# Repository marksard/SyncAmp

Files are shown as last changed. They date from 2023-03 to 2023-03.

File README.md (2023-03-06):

# Synthesizer Sync Output Voltage Amplifier

A comparator-type amplifier that provides 5V Sync voltage for small instruments such as Teenage Engineering PO-32 and Paripi Destroyer.

[blog](https://marksard.github.io/2023/02/23/make-line-mixer/)

  
  

## Usage

Connect to SyncIn from a small instrument such as Teenage Engineering PO-32, Paripi Destroyer, etc.  
From Sync Out, connect to the instrument with Sync In.  
Adjust the Threshold knob until the LED flashes moderately in time with the pulse of the Sync voltage. If it syncs, you have succeeded.  

## Spec

### Input

3.5mm phone jack (TS)  
DC input is available.  

### Thresold Setting

As known as V ref.  
Range of values 0V to 2.5V.  

### Output

3.5mm phone jack (TS)  
Range of values 0V to 4.7V.  

### Power supply

- 9V

## Schematic



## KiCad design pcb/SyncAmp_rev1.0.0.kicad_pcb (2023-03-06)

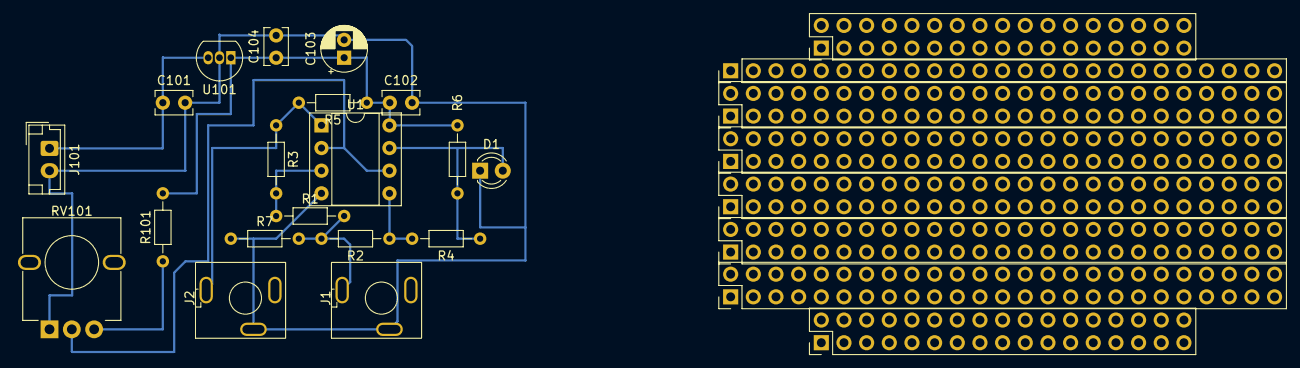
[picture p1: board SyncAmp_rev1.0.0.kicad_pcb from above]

Board: 2 copper layers, 19 parts (0 on the bottom side), 10 nets.

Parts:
C101: 0.33u; C_Rect_L4.0mm_W2.5mm_P2.50mm
C102, C104: 0.1u; C_Rect_L4.0mm_W2.5mm_P2.50mm
C103: 47u; CP_Radial_D5.0mm_P2.00mm
D1: LED; LED_D3.0mm
J1: Sync In; MJ-355W
J2: Sync Out; MJ-355W
J101: Barrel_Jack; JST_EH_B2B-EH-A_1x02_P2.50mm_Vertical
R1, R2, R7, R101: 10k; R_Axial_DIN0204_L3.6mm_D1.6mm_P7.62mm_Horizontal
R3, R4: 10Meg; R_Axial_DIN0204_L3.6mm_D1.6mm_P7.62mm_Horizontal
R5, R6: 3k; R_Axial_DIN0204_L3.6mm_D1.6mm_P7.62mm_Horizontal
RV101: B10k; Potentiometer_THT_RK09L1140
U1: LM393; DIP-8_W7.62mm_Socket
U101: LM78L05_TO92; TO-92_Inline

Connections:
/in: J1.T, R1.2, R2.2, R7.2
/out: J2.T, R3.1, R5.2, U1.1
GND: C101.2, C102.2, C103.2, C104.2, D1.1 (K), J1.S, J2.S, J101.2, R7.1, RV101.1, U1.4 (V-), U101.2 (GND)
unnamed: C101.1, J101.1, U101.3 (VI)
unnamed: D1.2 (A), R4.1, R6.2, U1.7
unnamed: R1.1, R3.2, U1.3 (+)
unnamed: R2.1, R4.2, U1.5 (+)
unnamed: R101.1, RV101.3
VCC: C102.1, C103.1, C104.1, R5.1, R6.1, R101.2, U1.8 (V+), U101.1 (VO)
vref: RV101.2, U1.2 (-), U1.6 (-)
